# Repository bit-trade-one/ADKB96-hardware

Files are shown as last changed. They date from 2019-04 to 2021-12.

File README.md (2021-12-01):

# ADKB96

## [The production method manual is here! ](http://bit-trade-one.co.jp/selfmadekb/adkb96manual/) (Sorry, now japanese only ...)

### [Firmware writing procedure (external site)](https://bit-trade-one.co.jp/selfmadekb/softwaremanual/)

main  
ADKB96  
ADKB96  
## Standard 96 key type base model.

It is a standard rectangle (rectangular) base model of vertical 6 x horizontal 16 keys.
Recommended for those who want to make it first, and those who want to stick to the type of key in orthodox form.
Comfortable to use as a tester with various switches and key tops.

## Compact and easy to carry. Also supports tilt.

The compact acrylic case with a thickness of 20 mm is easy to handle and matches various desks.
Use of the tilt is also possible by using the included stand.

## please note!

To use this product, you need a general knowledge of electronic work and electronic circuits. Also, key tops and key switches are not included.
Please prepare your own by yourself.

### <Product specification>

- Supported interface: USB MicroB
- Maximum number of keys: 96
- Supported key switch: Cherry MX / Kailh Low Profile
- Body size 310 x D 115 x H 20 mm
- Weight: about 300g ※ The dimensions and weight are measured with the kit only
- Operating environment: Temperature: 0 to 45 ° C, humidity 10 to 60% (thing without condensation)
- Contents: complete set / parts list & preparation manual guide 1 part / kit repair guide 1 part
- Producing country: Made in Japan
- Warranty period: Only initial failure of parts is supported. Operation after assembly is not covered by warranty.

| Part name | Quantity |
|:-: |:-: |
| * Pro Micro compatible products (firmware has been written) | 2 |
| Diode 1N4148 (THD) | 96 |
| Tact switch | 2 |
| * Micro USB Cable | 1 |
| Spacer | 14 |
| Screw | 28 |
| Cushion rubber seal | 8 |
| Round washer | 4 |
| Substrate | 1 |
| Acrylic set | 1 |

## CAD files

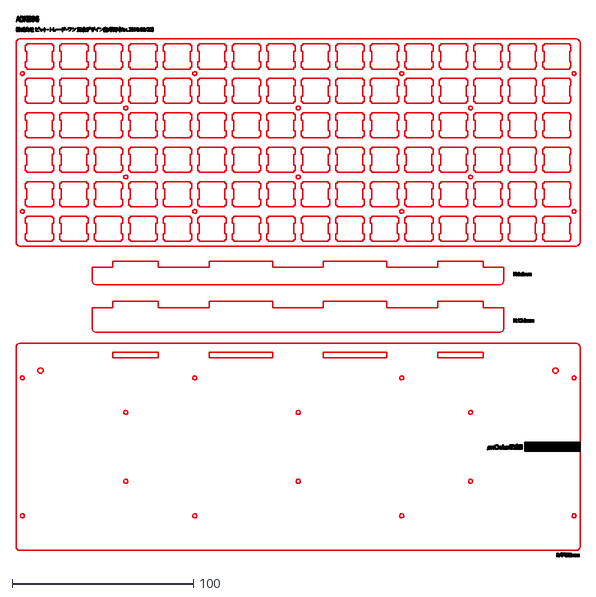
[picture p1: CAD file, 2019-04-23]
ADKB96-AKRL-FIX/ADKB96-AKRL-FIX.dxf
310.8 x 298.1

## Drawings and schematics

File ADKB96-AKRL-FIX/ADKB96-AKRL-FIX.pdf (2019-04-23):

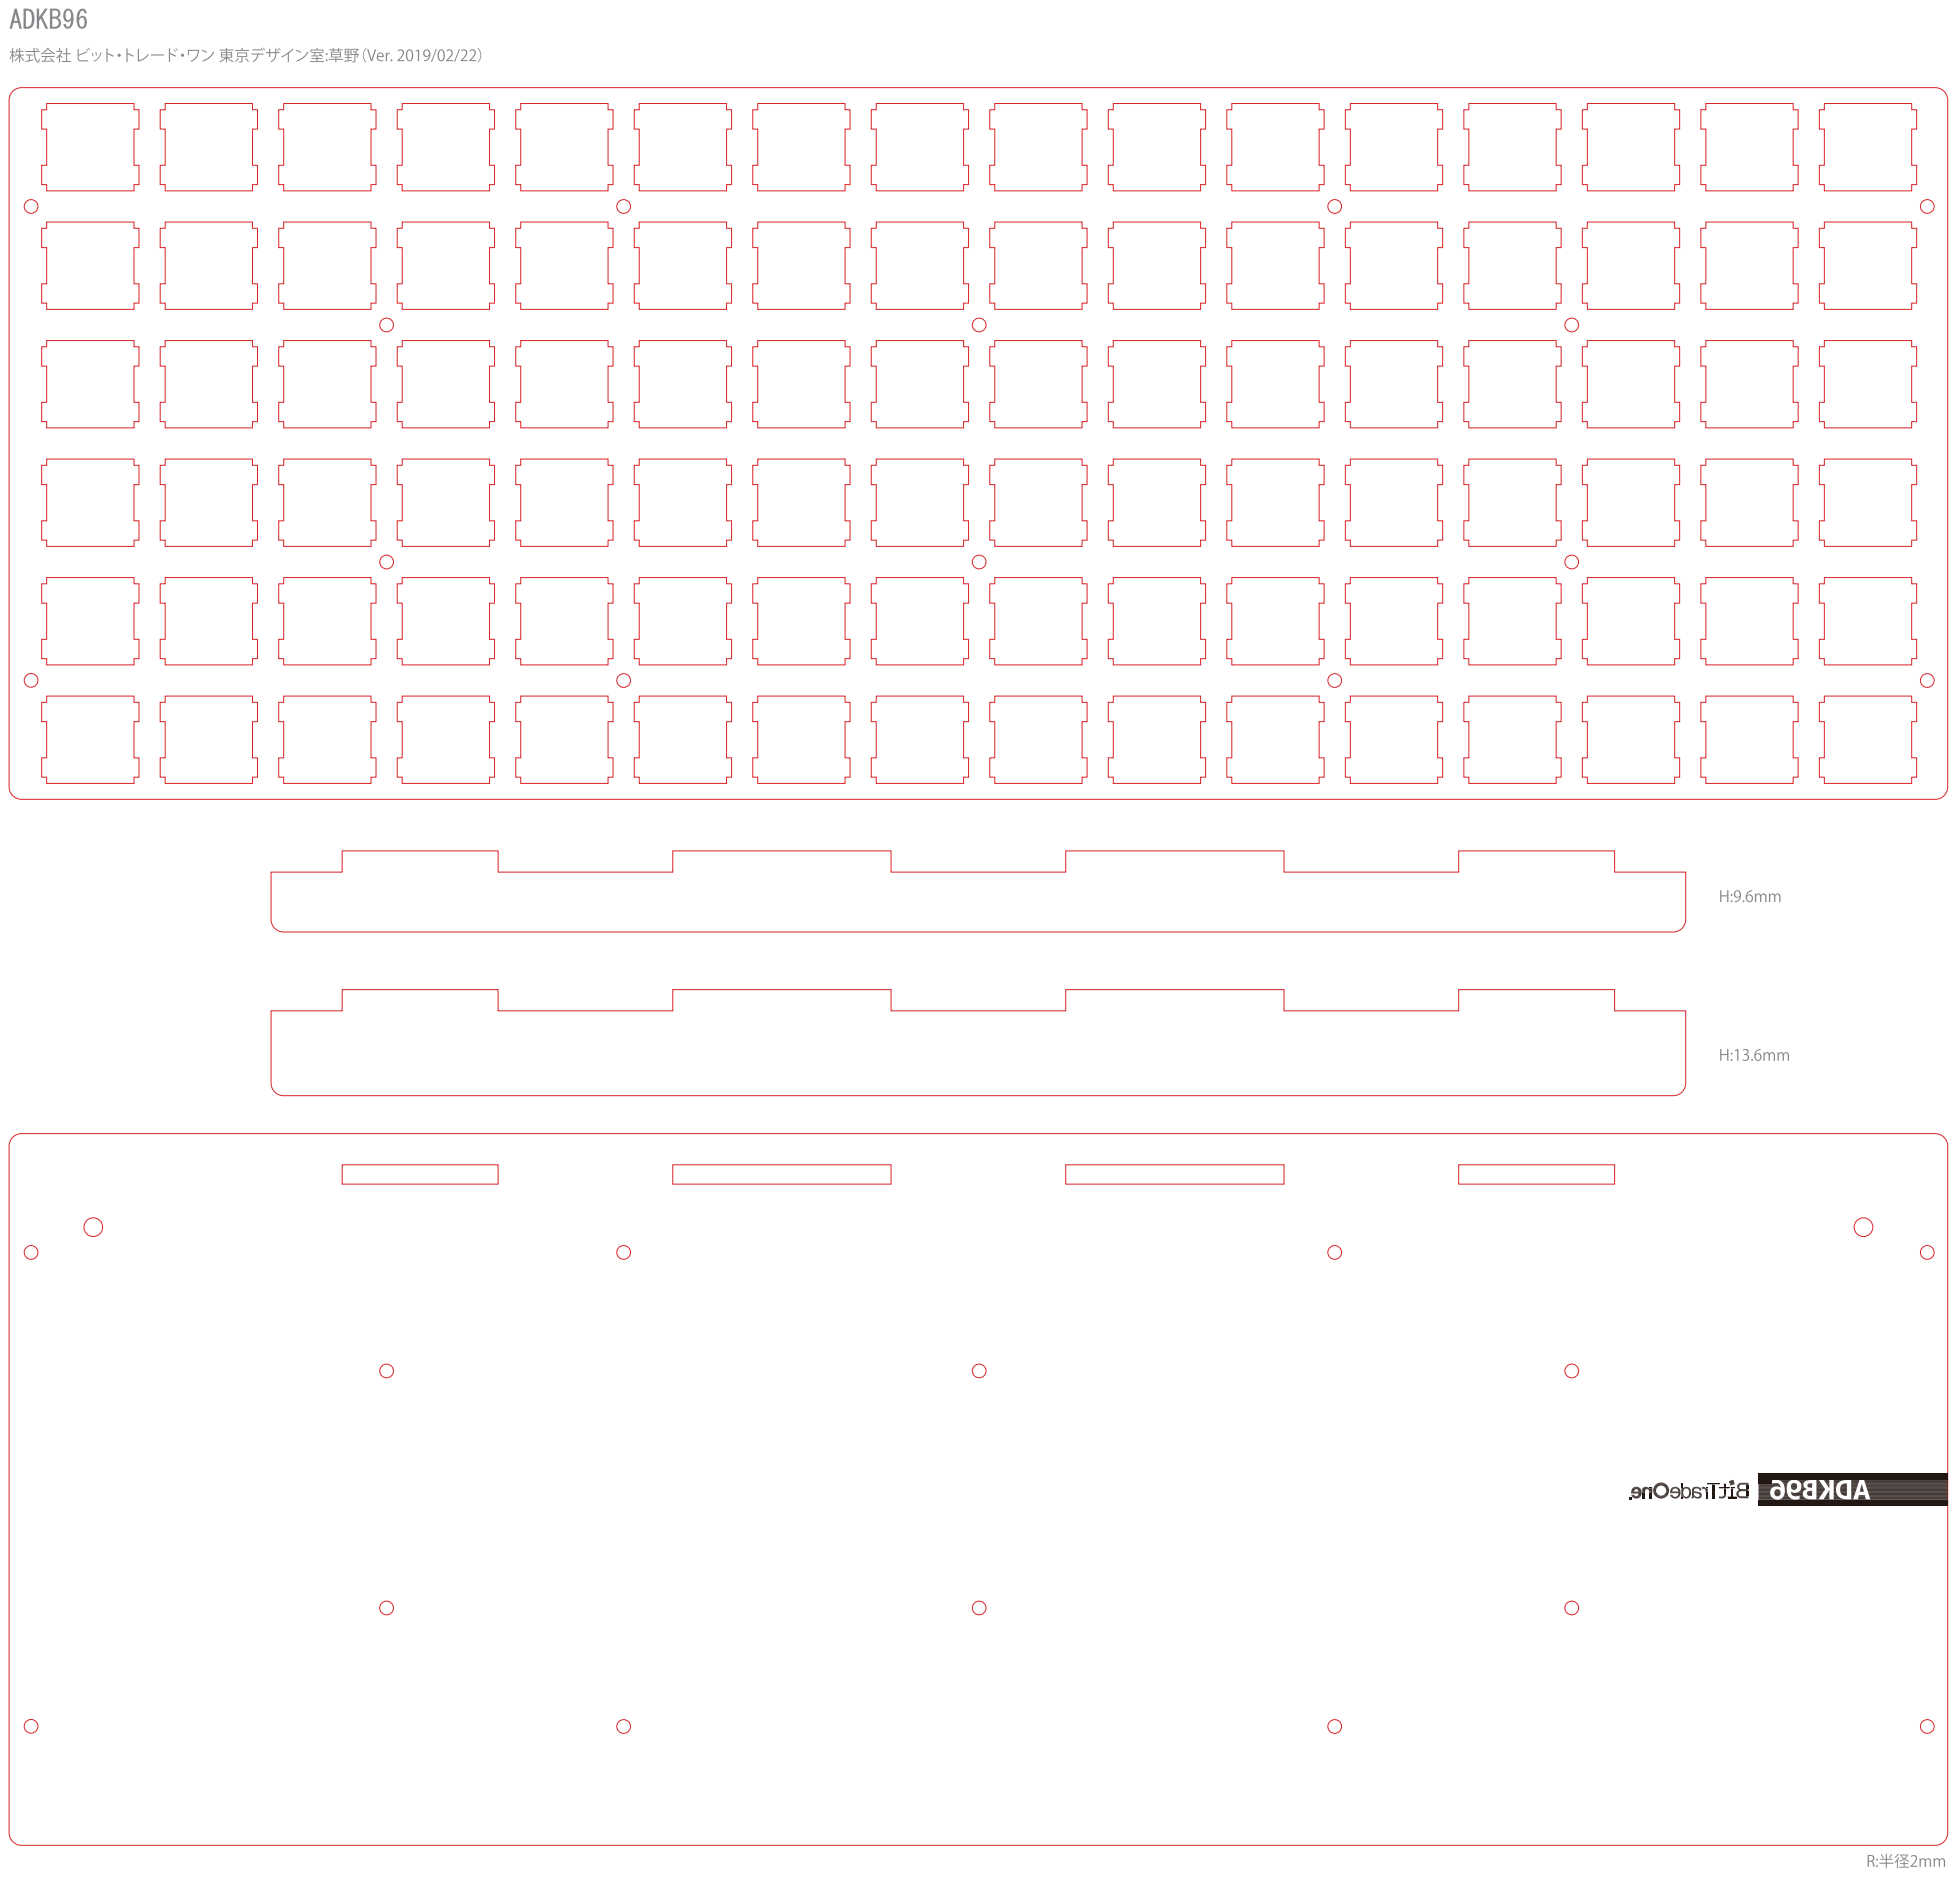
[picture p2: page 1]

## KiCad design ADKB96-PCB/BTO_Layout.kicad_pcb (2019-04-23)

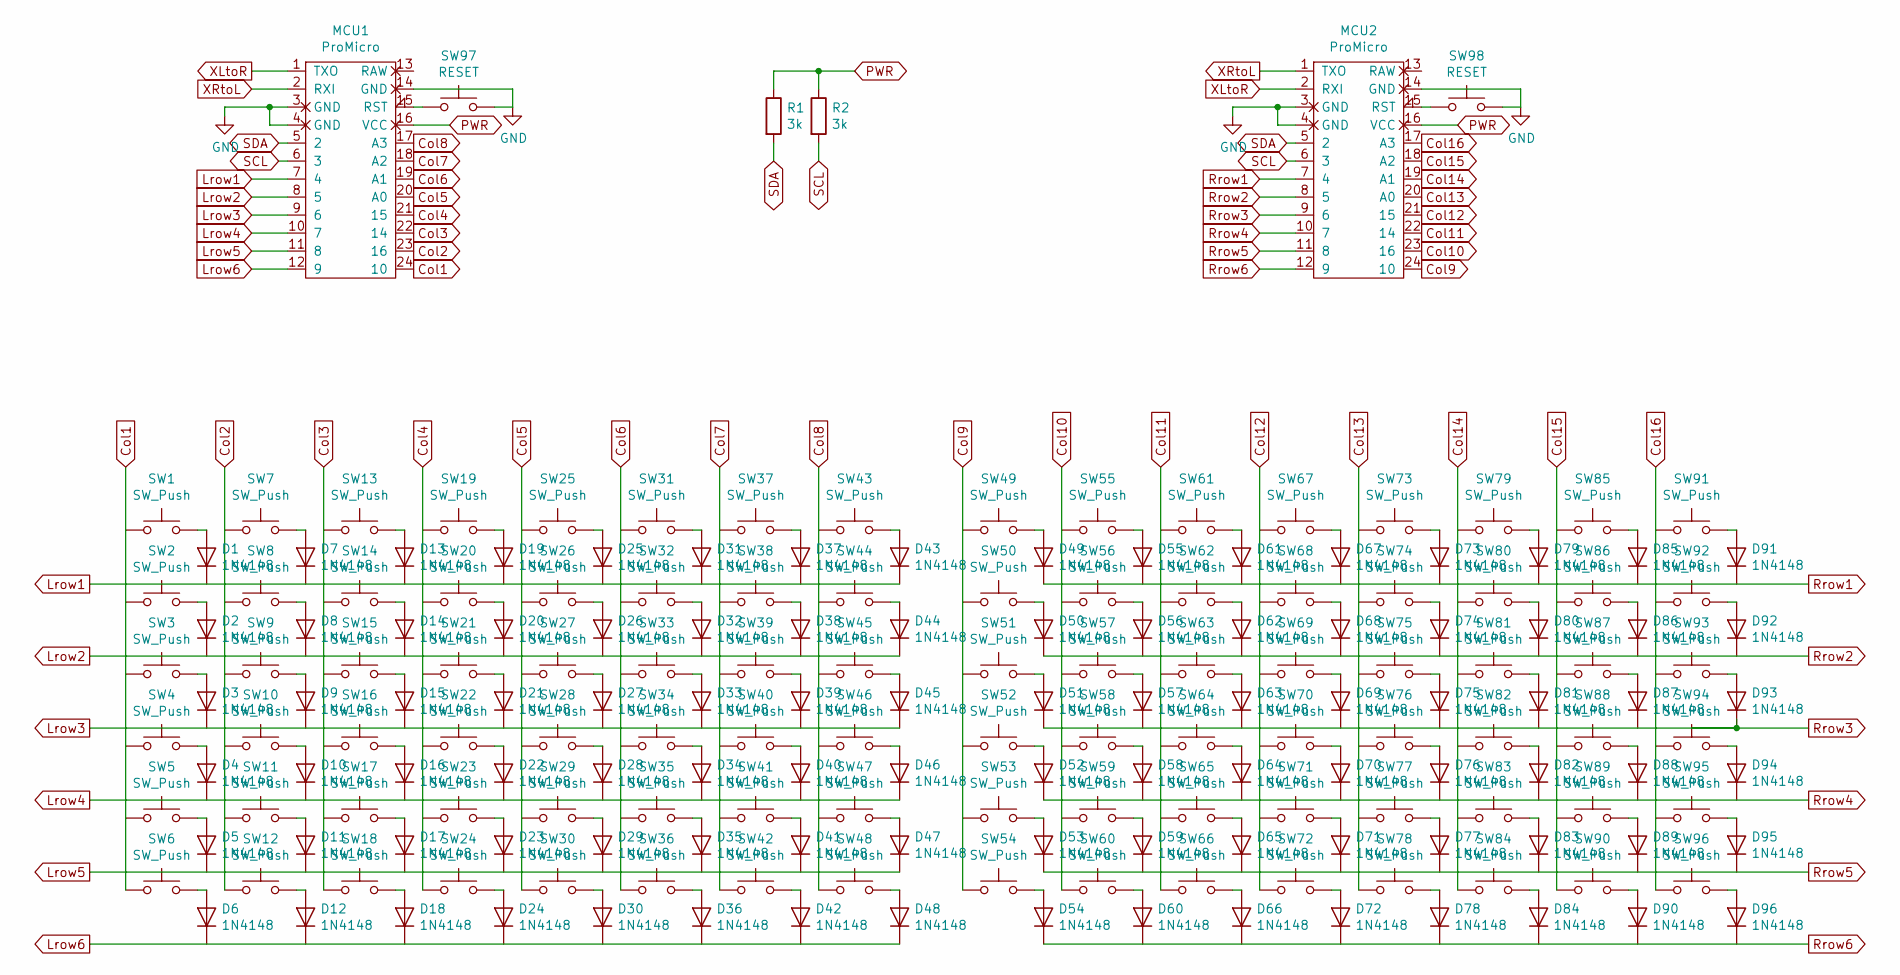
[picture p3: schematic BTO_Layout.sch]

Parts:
D1, D2, D3, D4, D5, D6, D7, D8, D9, D10, D11, D12, D13, D14, D15, D16, D17, D18, D19, D20, D21, D22, D23, D24, D25, D26, D27, D28, D29, D30, D31, D32, D33, D34, D35, D36, D37, D38, D39, D40, D41, D42, D43, D44, D45, D46, D47, D48, D49, D50, D51, D52, D53, D54, D55, D56, D57, D58, D59, D60, D61, D62, D63, D64, D65, D66, D67, D68, D69, D70, D71, D72, D73, D74, D75, D76, D77, D78, D79, D80, D81, D82, D83, D84, D85, D86, D87, D88, D89, D90, D91, D92, D93, D94, D95, D96: 1N4148; Diode_Keyboard_10_16
MCU1, MCU2: ProMicro; Pro_Micro
R1, R2: 3k; R_Axial_DIN0207_L6.3mm_D2.5mm_P10.16mm_Horizontal
SW1, SW2, SW3, SW4, SW5, SW6, SW7, SW8, SW9, SW10, SW11, SW12, SW13, SW14, SW15, SW16, SW17, SW18, SW19, SW20, SW21, SW22, SW23, SW24, SW25, SW26, SW27, SW28, SW29, SW30, SW31, SW32, SW33, SW34, SW35, SW36, SW37, SW38, SW39, SW40, SW41, SW42, SW43, SW44, SW45, SW46, SW47, SW48, SW49, SW50, SW51, SW52, SW53, SW54, SW55, SW56, SW57, SW58, SW59, SW60, SW61, SW62, SW63, SW64, SW65, SW66, SW67, SW68, SW69, SW70, SW71, SW72, SW73, SW74, SW75, SW76, SW77, SW78, SW79, SW80, SW81, SW82, SW83, SW84, SW85, SW86, SW87, SW88, SW89, SW90, SW91, SW92, SW93, SW94, SW95, SW96: SW_Push; SW_Cherry_Kailh_ALPS
SW97, SW98: RESET; SW_PUSH_6mm

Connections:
Col1: MCU1.24 (10), SW1.1, SW2.1, SW3.1, SW4.1, SW5.1, SW6.1
Col2: MCU1.23 (16), SW7.1, SW8.1, SW9.1, SW10.1, SW11.1, SW12.1
Col3: MCU1.22 (14), SW13.1, SW14.1, SW15.1, SW16.1, SW17.1, SW18.1
Col4: MCU1.21 (15), SW19.1, SW20.1, SW21.1, SW22.1, SW23.1, SW24.1
Col5: MCU1.20 (A0), SW25.1, SW26.1, SW27.1, SW28.1, SW29.1, SW30.1
Col6: MCU1.19 (A1), SW31.1, SW32.1, SW33.1, SW34.1, SW35.1, SW36.1
Col7: MCU1.18 (A2), SW37.1, SW38.1, SW39.1, SW40.1, SW41.1, SW42.1
Col8: MCU1.17 (A3), SW43.1, SW44.1, SW45.1, SW46.1, SW47.1, SW48.1
Col9: MCU2.24 (10), SW49.1, SW50.1, SW51.1, SW52.1, SW53.1, SW54.1
Col10: MCU2.23 (16), SW55.1, SW56.1, SW57.1, SW58.1, SW59.1, SW60.1
Col11: MCU2.22 (14), SW61.1, SW62.1, SW63.1, SW64.1, SW65.1, SW66.1
Col12: MCU2.21 (15), SW67.1, SW68.1, SW69.1, SW70.1, SW71.1, SW72.1
Col13: MCU2.20 (A0), SW73.1, SW74.1, SW75.1, SW76.1, SW77.1, SW78.1
Col14: MCU2.19 (A1), SW79.1, SW80.1, SW81.1, SW82.1, SW83.1, SW84.1
Col15: MCU2.18 (A2), SW85.1, SW86.1, SW87.1, SW88.1, SW89.1, SW90.1
Col16: MCU2.17 (A3), SW91.1, SW92.1, SW93.1, SW94.1, SW95.1, SW96.1
GND: MCU1.3 (GND), MCU1.4 (GND), MCU1.14 (GND), MCU2.3 (GND), MCU2.4 (GND), MCU2.14 (GND), SW97.2, SW98.2
Lrow1: D1.1 (K), D7.1 (K), D13.1 (K), D19.1 (K), D25.1 (K), D31.1 (K), D37.1 (K), D43.1 (K), MCU1.7 (4)
Lrow2: D2.1 (K), D8.1 (K), D14.1 (K), D20.1 (K), D26.1 (K), D32.1 (K), D38.1 (K), D44.1 (K), MCU1.8 (5)
Lrow3: D3.1 (K), D9.1 (K), D15.1 (K), D21.1 (K), D27.1 (K), D33.1 (K), D39.1 (K), D45.1 (K), MCU1.9 (6)
Lrow4: D4.1 (K), D10.1 (K), D16.1 (K), D22.1 (K), D28.1 (K), D34.1 (K), D40.1 (K), D46.1 (K), MCU1.10 (7)
Lrow5: D5.1 (K), D11.1 (K), D17.1 (K), D23.1 (K), D29.1 (K), D35.1 (K), D41.1 (K), D47.1 (K), MCU1.11 (8)
Lrow6: D6.1 (K), D12.1 (K), D18.1 (K), D24.1 (K), D30.1 (K), D36.1 (K), D42.1 (K), D48.1 (K), MCU1.12 (9)
unnamed: D1.2 (A), SW1.2
unnamed: D2.2 (A), SW2.2
unnamed: D3.2 (A), SW3.2
unnamed: D4.2 (A), SW4.2
unnamed: D5.2 (A), SW5.2
unnamed: D6.2 (A), SW6.2
unnamed: D7.2 (A), SW7.2
unnamed: D8.2 (A), SW8.2
unnamed: D9.2 (A), SW9.2
unnamed: D10.2 (A), SW10.2
unnamed: D11.2 (A), SW11.2
unnamed: D12.2 (A), SW12.2
unnamed: D13.2 (A), SW13.2
unnamed: D14.2 (A), SW14.2
unnamed: D15.2 (A), SW15.2
unnamed: D16.2 (A), SW16.2
unnamed: D17.2 (A), SW17.2
unnamed: D18.2 (A), SW18.2
unnamed: D19.2 (A), SW19.2
unnamed: D20.2 (A), SW20.2
unnamed: D21.2 (A), SW21.2
unnamed: D22.2 (A), SW22.2
unnamed: D23.2 (A), SW23.2
unnamed: D24.2 (A), SW24.2
unnamed: D25.2 (A), SW25.2
unnamed: D26.2 (A), SW26.2
unnamed: D27.2 (A), SW27.2
unnamed: D28.2 (A), SW28.2
unnamed: D29.2 (A), SW29.2
unnamed: D30.2 (A), SW30.2
unnamed: D31.2 (A), SW31.2
unnamed: D32.2 (A), SW32.2
unnamed: D33.2 (A), SW33.2
unnamed: D34.2 (A), SW34.2
unnamed: D35.2 (A), SW35.2
unnamed: D36.2 (A), SW36.2
unnamed: D37.2 (A), SW37.2
unnamed: D38.2 (A), SW38.2
unnamed: D39.2 (A), SW39.2
unnamed: D40.2 (A), SW40.2
unnamed: D41.2 (A), SW41.2
unnamed: D42.2 (A), SW42.2
unnamed: D43.2 (A), SW43.2
unnamed: D44.2 (A), SW44.2
unnamed: D45.2 (A), SW45.2
unnamed: D46.2 (A), SW46.2
unnamed: D47.2 (A), SW47.2
unnamed: D48.2 (A), SW48.2
unnamed: D49.2 (A), SW49.2
unnamed: D50.2 (A), SW50.2
unnamed: D51.2 (A), SW51.2
unnamed: D52.2 (A), SW52.2
unnamed: D53.2 (A), SW53.2
unnamed: D54.2 (A), SW54.2
unnamed: D55.2 (A), SW55.2
unnamed: D56.2 (A), SW56.2
unnamed: D57.2 (A), SW57.2
unnamed: D58.2 (A), SW58.2
unnamed: D59.2 (A), SW59.2
unnamed: D60.2 (A), SW60.2
unnamed: D61.2 (A), SW61.2
unnamed: D62.2 (A), SW62.2
unnamed: D63.2 (A), SW63.2
unnamed: D64.2 (A), SW64.2
unnamed: D65.2 (A), SW65.2
unnamed: D66.2 (A), SW66.2
unnamed: D67.2 (A), SW67.2
unnamed: D68.2 (A), SW68.2
unnamed: D69.2 (A), SW69.2
unnamed: D70.2 (A), SW70.2
unnamed: D71.2 (A), SW71.2
unnamed: D72.2 (A), SW72.2
unnamed: D73.2 (A), SW73.2
unnamed: D74.2 (A), SW74.2
unnamed: D75.2 (A), SW75.2
unnamed: D76.2 (A), SW76.2
unnamed: D77.2 (A), SW77.2
unnamed: D78.2 (A), SW78.2
unnamed: D79.2 (A), SW79.2
unnamed: D80.2 (A), SW80.2
unnamed: D81.2 (A), SW81.2
unnamed: D82.2 (A), SW82.2
unnamed: D83.2 (A), SW83.2
unnamed: D84.2 (A), SW84.2
unnamed: D85.2 (A), SW85.2
unnamed: D86.2 (A), SW86.2
unnamed: D87.2 (A), SW87.2
unnamed: D88.2 (A), SW88.2
unnamed: D89.2 (A), SW89.2
unnamed: D90.2 (A), SW90.2
unnamed: D91.2 (A), SW91.2
unnamed: D92.2 (A), SW92.2
unnamed: D93.2 (A), SW93.2
unnamed: D94.2 (A), SW94.2
unnamed: D95.2 (A), SW95.2
unnamed: D96.2 (A), SW96.2
unnamed: MCU1.15 (RST), SW97.1
unnamed: MCU2.15 (RST), SW98.1
PWR: MCU1.16 (VCC), MCU2.16 (VCC), R1.1, R2.1
Rrow1: D49.1 (K), D55.1 (K), D61.1 (K), D67.1 (K), D73.1 (K), D79.1 (K), D85.1 (K), D91.1 (K), MCU2.7 (4)
Rrow2: D50.1 (K), D56.1 (K), D62.1 (K), D68.1 (K), D74.1 (K), D80.1 (K), D86.1 (K), D92.1 (K), MCU2.8 (5)
Rrow3: D51.1 (K), D57.1 (K), D63.1 (K), D69.1 (K), D75.1 (K), D81.1 (K), D87.1 (K), D93.1 (K), MCU2.9 (6)
Rrow4: D52.1 (K), D58.1 (K), D64.1 (K), D70.1 (K), D76.1 (K), D82.1 (K), D88.1 (K), D94.1 (K), MCU2.10 (7)
Rrow5: D53.1 (K), D59.1 (K), D65.1 (K), D71.1 (K), D77.1 (K), D83.1 (K), D89.1 (K), D95.1 (K), MCU2.11 (8)
Rrow6: D54.1 (K), D60.1 (K), D66.1 (K), D72.1 (K), D78.1 (K), D84.1 (K), D90.1 (K), D96.1 (K), MCU2.12 (9)
SCL: MCU1.6 (3), MCU2.6 (3), R2.2
SDA: MCU1.5 (2), MCU2.5 (2), R1.2
XLtoR: MCU1.1 (TXO), MCU2.2 (RXI)
XRtoL: MCU1.2 (RXI), MCU2.1 (TXO)

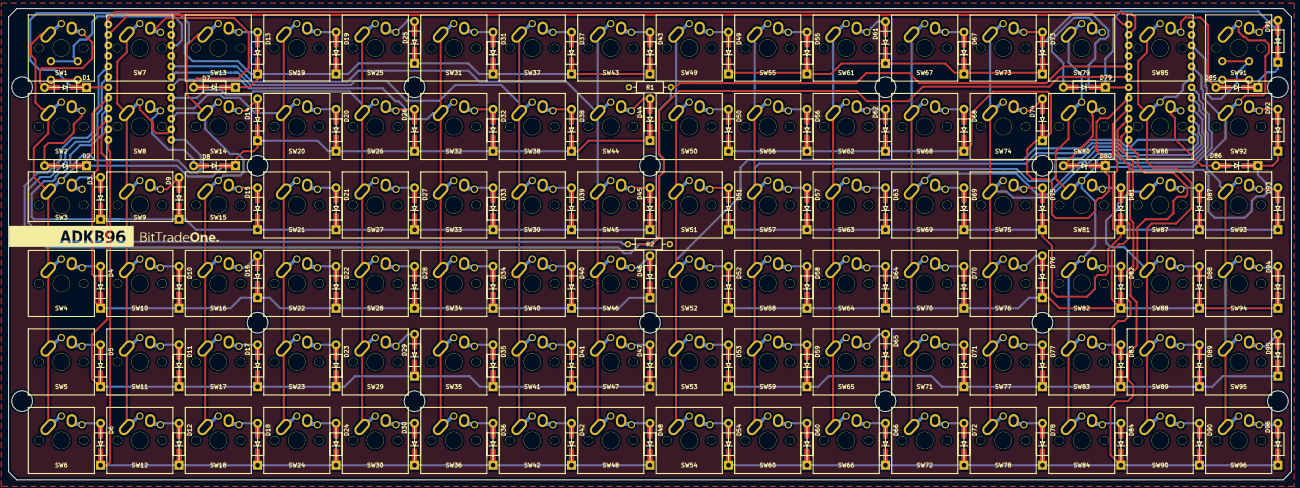
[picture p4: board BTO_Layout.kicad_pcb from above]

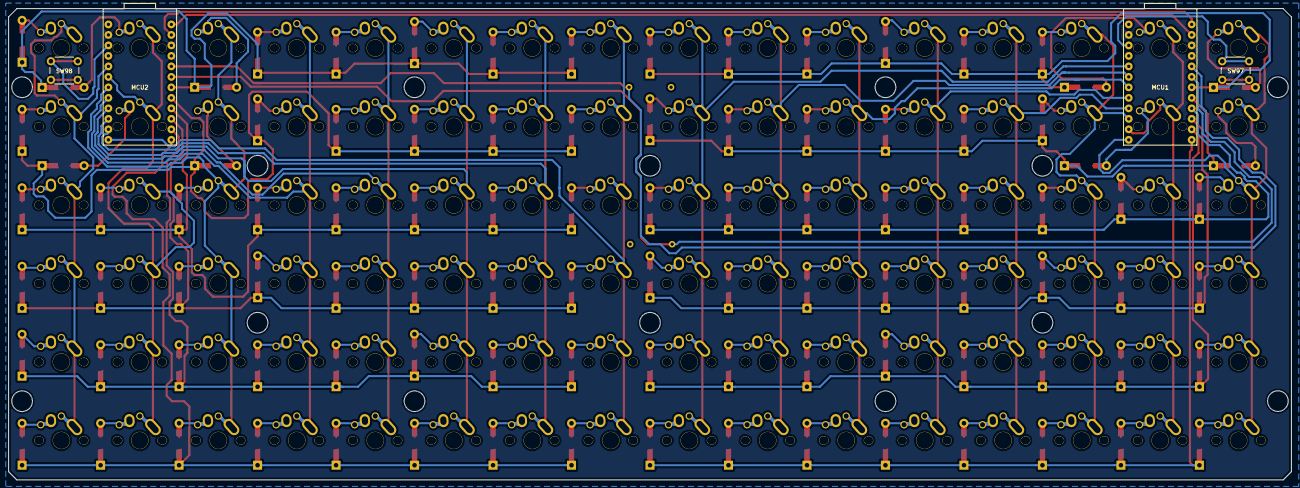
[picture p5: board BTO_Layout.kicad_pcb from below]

Board: 2 copper layers, 310.6 x 114.1 mm, 198 parts (2 on the bottom side), 132 nets.
